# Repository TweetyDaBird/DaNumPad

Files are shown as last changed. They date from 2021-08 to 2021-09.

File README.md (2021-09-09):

## Notice!!! 
#### DaNumPad is currently under active development! Clone/Build at your own peril! Update will follow when the design has been fully build-tested!

# DaNumPad
A 'family' of mechanical numpad/macro pads that can be configured either as a classic 17-key numpad, or as a 20 key (5x4) macro pad.

- USB-C connector
- Cherry MX compatible switches
- Kailh Hotswap sockets
- Supports PCB-mounted Cherry style stabilizers
- Designed as a companion to most 60% keyboards, being the same 5 row 'height'.
- Sandwich case with top and bottom plate from FR4 material.
- Full SMD design, adapted to easily allow both SMT manufacturing and handsoldering.

## DaNumPad unWired & DaNumPad Glow
Available as two variations, wired and wireless with identical footprint, using the same plate but different PCB.

#### DaNumPad 17 Glow
- Classic 17-Key Numpad layout
- Atmega32u4 MCU
- Full Per-Key RGB
- QMK compatible

#### DaNumPad 20 Glow
- 20-Key macropad with two optional spots for rotary encoders.
- Atmega32u4 MCU
- Full Per-Key RGB
- QMK compatible

#### DaNumPad unWired
- 20-Key macropad with two optional spots for rotary encoders.
- Optional 17-Key layout on the same PCB (Requires soldering hotswap sockets on alternate placing)
- Wireless using an nRF85420 MCU
- ZMK compatible (Bluetooth)
- Can use a QMK compatible, 2.4Ghz Wireless dongle for lower latency/battery consumption. (Under development!)

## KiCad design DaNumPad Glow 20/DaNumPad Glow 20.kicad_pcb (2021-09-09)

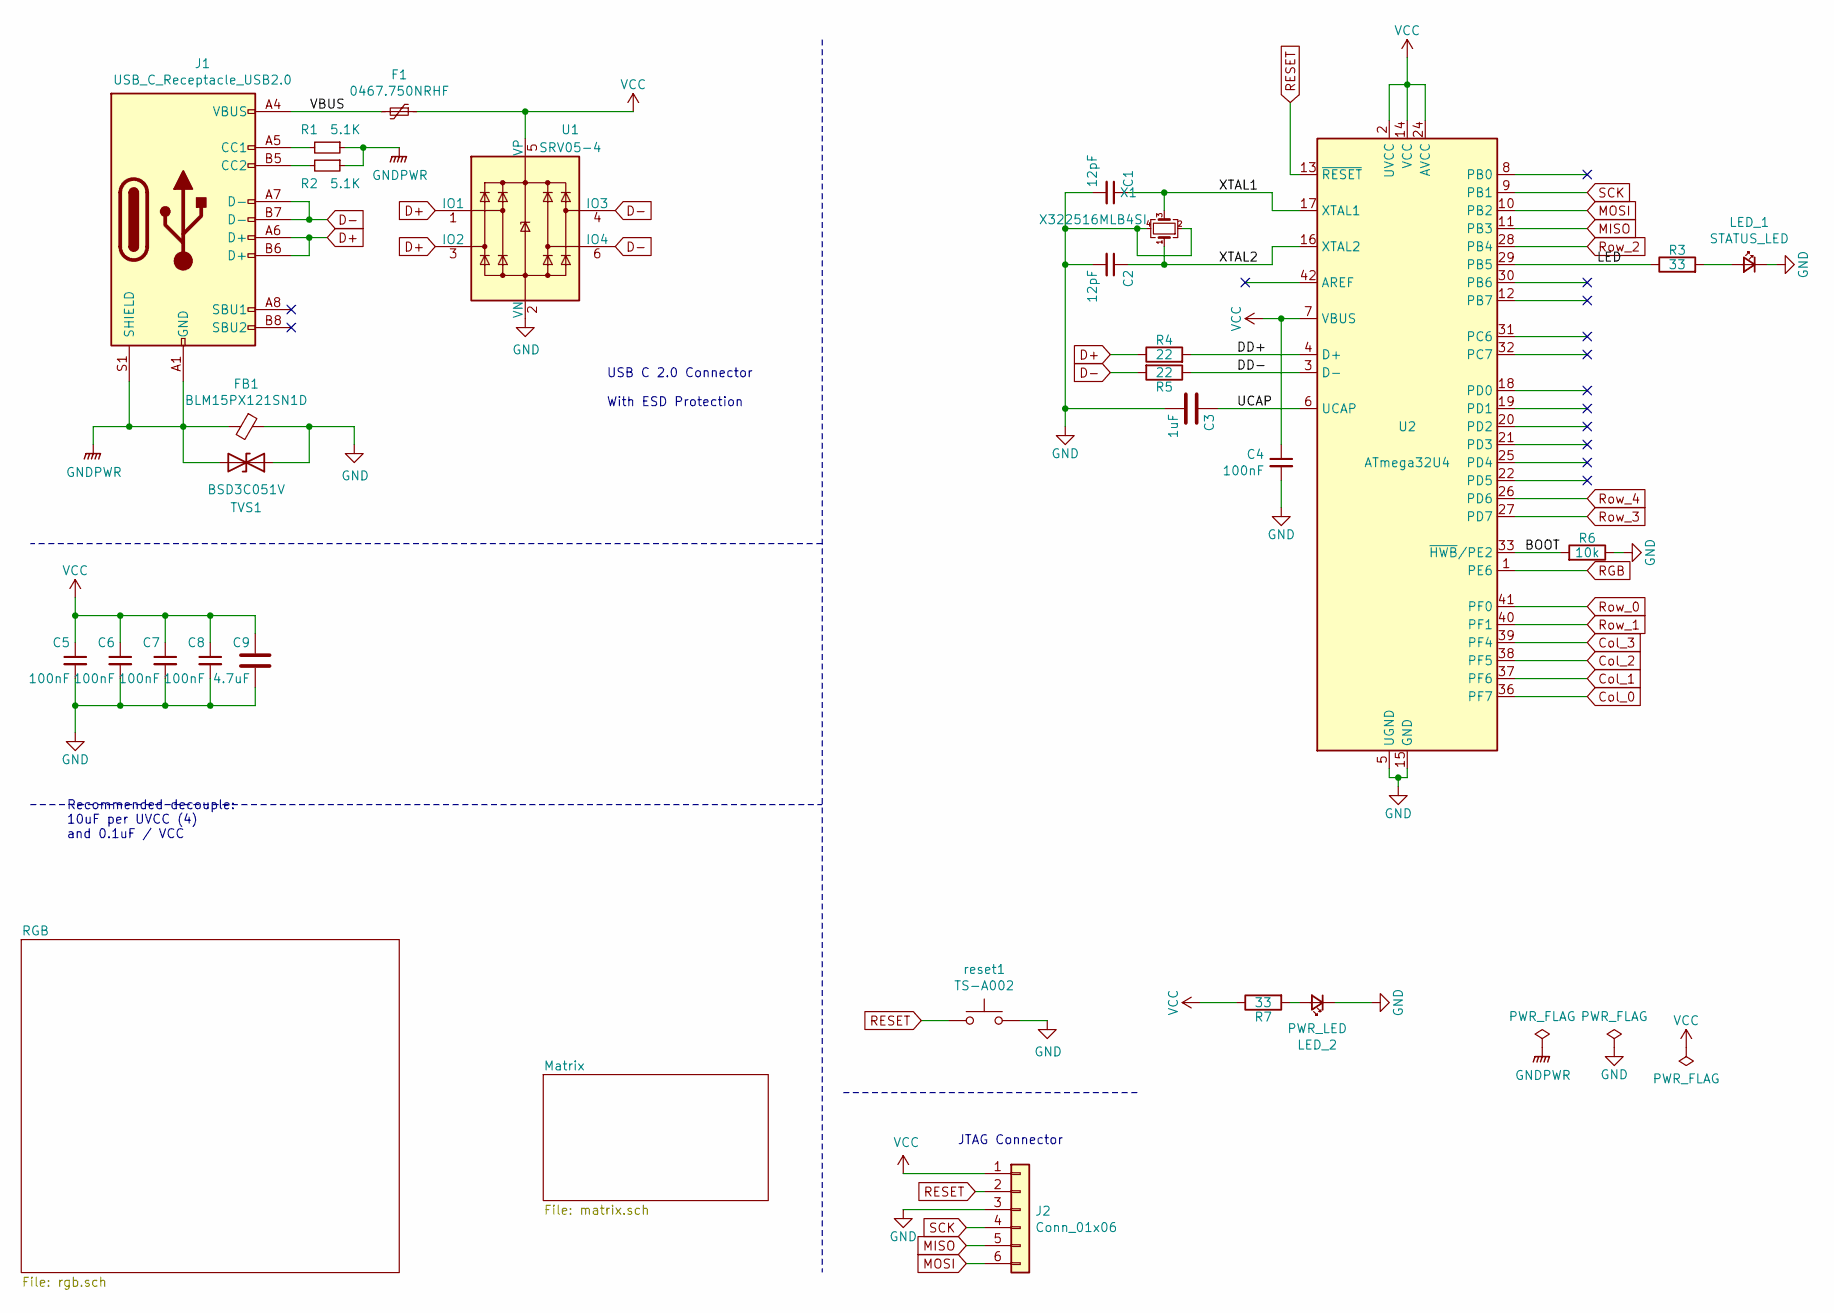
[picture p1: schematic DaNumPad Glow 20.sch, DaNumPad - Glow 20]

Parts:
C1, C2: 12pF; C_0603_1608Metric; Manufacturer_Part_Number CL10C120JB8NNNC; Mouser Part Number 581-06035A220J
C3: 1uF; C_0805_2012Metric; Manufacturer_Part_Number CL21B105KBFNNNE; Mouser Part Number 187-CL21B105KBFNNNG
C4, C5, C6, C7, C8: 100nF; C_0603_1608Metric; Manufacturer_Part_Number CC0603KRX7R9BB104; Mouser Part Number 581-06035C104JAT2A
C9: 4.7uF; C_0805_2012Metric; Manufacturer_Part_Number CL21A475KAQNNNE; Mouser Part Number 810-C2012X7R475K125C
F1: 0467.750NRHF; Fuse_0603_1608Metric_Castellated; Manufacturer_Part_Number 0467.750NRHF; LCSC C206991
FB1: BLM15PX121SN1D; R_0402_1005Metric_Pad0.72x0.64mm_HandSolder; Manufacturer_Part_Number BLM15PX121SN1D11; LCSC C88970
J1: USB_C_Receptacle_USB2.0; USB_C_Receptacle_HRO_TYPE-C-31-M-12; Manufacturer_Part_Number TYPE-C-31-M-12; LCSC C165948
J2: Conn_01x06; PinHeader_2x03_P2.54mm_Vertical
LED_1: STATUS_LED; LED_0603_1608Metric; Manufacturer_Part_Number KT-0603R; Mouser Part Number 604-APT1608EC
LED_2: PWR_LED; LED_0603_1608Metric; Manufacturer_Part_Number KT-0603R; Mouser Part Number 604-APT1608EC
R1, R2: 5.1K; R_0603_1608Metric; Manufacturer_Part_Number 0603WAF5101T5E; LCSC C23186
R3, R7: 33; R_0603_1608Metric; Manufacturer_Part_Number 0603WAF330JT5E; Mouser Part Number 667-ERJ-3EKF33R0V
R4, R5: 22; R_0603_1608Metric; Manufacturer_Part_Number 0603WAF220JT5E; Mouser Part Number 667-ERJ-3GEYJ220V
R6: 10k; R_0603_1608Metric; Manufacturer_Part_Number 0603WAF1002T5E; Mouser Part Number 667-ERJ-3GEYJ103V
TVS1: BSD3C051V; D_SOD-323; Manufacturer_Part_Number BSD3C051V; LCSC C151996
U1: SRV05-4; SOT-23-6; Manufacturer_Part_Number SRV05-4-P-T7; LCSC C85364
U2: ATmega32U4; QFN-44-1EP_7x7mm_P0.5mm_EP5.15x5.15mm; Manufacturer_Part_Number ATMEGA32U4-MU; Mouser Part Number 556-ATMEGA32U4RC-MU
X1: X322516MLB4SI; Crystal_SMD_3225-4Pin_3.2x2.5mm_HandSoldering; Mouser Part Number 81-XRCGB16M000FXN00R
reset1: TS-A002; SW_SPST_CK_RS282G05A3

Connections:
/BOOT: R6.2, U2.33 (~HWB~/PE2)
/DD+: R4.2, U2.4 (D+)
/DD-: R5.1, U2.3 (D-)
/LED: R3.1, U2.29 (PB5)
/UCAP: C3.1, U2.6 (UCAP)
/VBUS: F1.2, J1.A4 (VBUS), J1.A9 (VBUS), J1.B4 (VBUS), J1.B9 (VBUS)
/XTAL1: C1.1, U2.17 (XTAL1), X1.3
/XTAL2: C2.1, U2.16 (XTAL2), X1.1
Col_0: U2.36 (PF7); also elsewhere on the board
Col_1: U2.37 (PF6); also elsewhere on the board
Col_2: U2.38 (PF5); also elsewhere on the board
D+: J1.A6 (D+), J1.B6 (D+), R4.1, U1.1 (IO1), U1.3 (IO2)
D-: J1.A7 (D-), J1.B7 (D-), R5.2, U1.4 (IO3), U1.6 (IO4)
GND: C1.2, C2.2, C3.2, C4.2, C5.2, C6.2, C7.2, C8.2, C9.2, FB1.1, J2.3, LED_1.1 (K), LED_2.1 (K), R6.1, TVS1.1 (A1), U1.2 (VN), U2.5 (UGND), U2.15 (GND), U2.23 (GND), U2.35 (GND), U2.43 (GND), X1.2, X1.4, reset1.2; also elsewhere on the board
GNDPWR: FB1.2, J1.A1 (GND), J1.A12 (GND), J1.B1 (GND), J1.B12 (GND), J1.S1 (SHIELD), R1.1, R2.1, TVS1.2 (A2)
MISO: J2.5, U2.11 (PB3)
MOSI: J2.6, U2.10 (PB2)
unnamed: J1.A5 (CC1), R1.2
unnamed: J1.B5 (CC2), R2.2
unnamed: LED_1.2 (A), R3.2
unnamed: LED_2.2 (A), R7.2
RESET: J2.2, U2.13 (~RESET), reset1.1
RGB: U2.1 (PE6); also elsewhere on the board
Row_0: U2.41 (PF0); also elsewhere on the board
Row_1: U2.40 (PF1); also elsewhere on the board
Row_2: U2.28 (PB4); also elsewhere on the board
Row_3: U2.27 (PD7); also elsewhere on the board
Row_4: U2.26 (PD6); also elsewhere on the board
SCK: J2.4, U2.9 (PB1)
VCC: C4.1, C5.1, C6.1, C7.1, C8.1, C9.1, F1.1, J2.1, R7.1, U1.5 (VP), U2.2 (UVCC), U2.7 (VBUS), U2.14 (VCC), U2.24 (AVCC), U2.34 (VCC), U2.44 (AVCC); also elsewhere on the board

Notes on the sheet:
USB C 2.0 Connector With ESD Protection
Recommended decouple: 10uF per UVCC (4) and 0.1uF / VCC
JTAG Connector

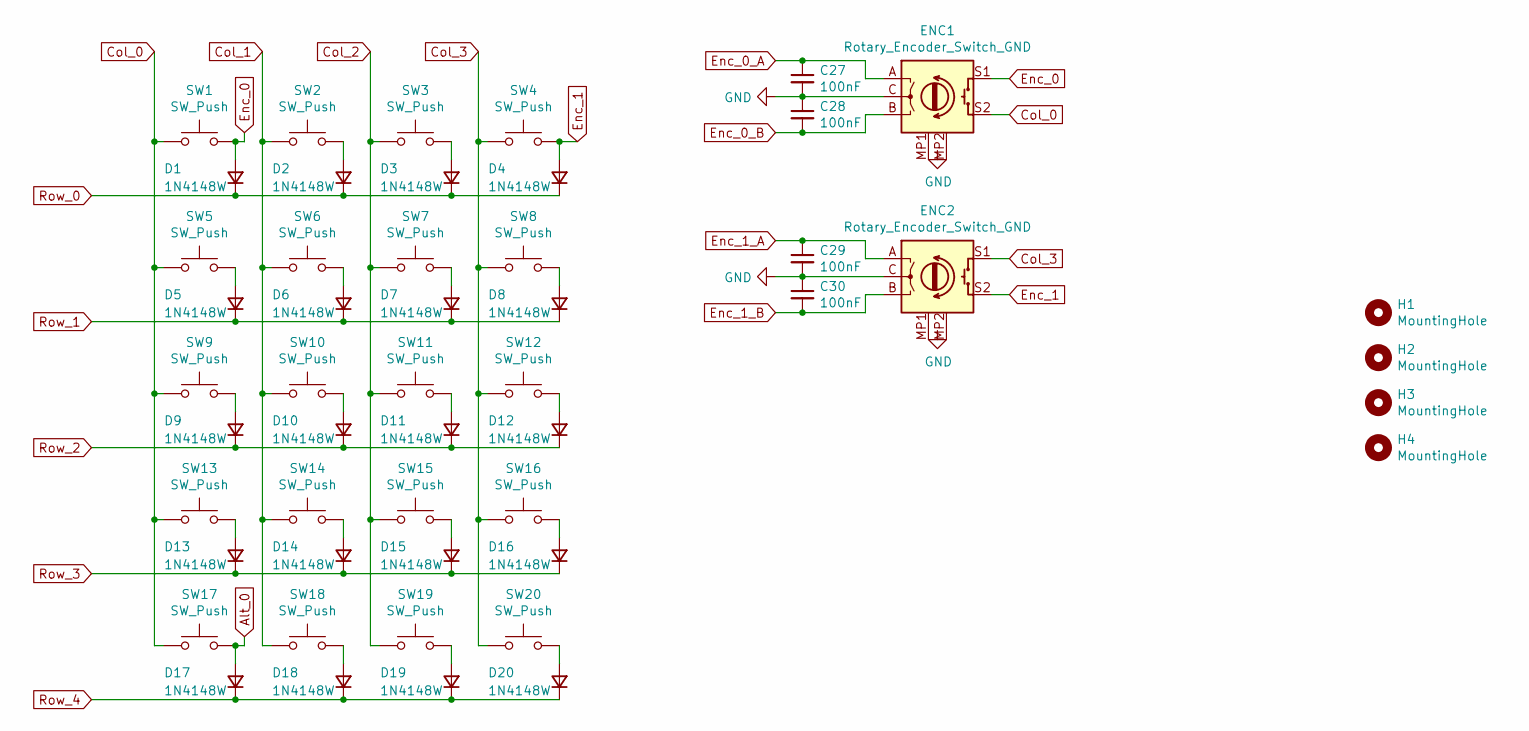
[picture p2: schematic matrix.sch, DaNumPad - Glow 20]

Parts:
C27, C28, C29, C30: 100nF; C_0603_1608Metric; Manufacturer_Part_Number CC0603KRX7R9BB104; LCSC C14663
D1, D2, D3, D4, D5, D6, D7, D8, D9, D10, D11, D12, D13, D14, D15, D16, D17, D18, D19, D20: 1N4148W; D_SOD-123; Manufacturer_Part_Number 1N4148W; LCSC C81598
ENC1, ENC2: Rotary_Encoder_Switch_GND; RotaryEncoder_Alps_EC11E-Switch_Vertical_H20mm
H1, H2, H3, H4: MountingHole; MountingHole_3.7mm
SW1, SW2, SW3, SW4, SW5, SW6, SW7, SW8, SW9, SW10, SW11, SW12, SW13, SW14, SW15, SW16, SW17, SW18, SW19, SW20: SW_Push; Kailh_socket_MX_RGB

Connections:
Alt_0: D17.2 (A), SW17.2
Col_0: ENC1.S2, SW1.1, SW5.1, SW9.1, SW13.1, SW17.1; also elsewhere on the board
Col_1: SW2.1, SW6.1, SW10.1, SW14.1, SW18.1; also elsewhere on the board
Col_2: SW3.1, SW7.1, SW11.1, SW15.1, SW19.1; also elsewhere on the board
Enc_0: D1.2 (A), ENC1.S1, SW1.2
Enc_0_A: C27.1, ENC1.A
Enc_0_B: C28.2, ENC1.B
Enc_1_A: C29.1, ENC2.A
Enc_1_B: C30.2, ENC2.B
GND: C27.2, C28.1, C29.2, C30.1, ENC1.C, ENC1.MP2 (GND), ENC2.C, ENC2.MP2 (GND); also elsewhere on the board
unnamed: D2.2 (A), SW2.2
unnamed: D3.2 (A), SW3.2
unnamed: D5.2 (A), SW5.2
unnamed: D6.2 (A), SW6.2
unnamed: D7.2 (A), SW7.2
unnamed: D9.2 (A), SW9.2
unnamed: D10.2 (A), SW10.2
unnamed: D11.2 (A), SW11.2
unnamed: D12.2 (A), SW12.2
unnamed: D13.2 (A), SW13.2
unnamed: D14.2 (A), SW14.2
unnamed: D15.2 (A), SW15.2
unnamed: D18.2 (A), SW18.2
unnamed: D19.2 (A), SW19.2
unnamed: D20.2 (A), SW20.2
Row_0: D1.1 (K), D2.1 (K), D3.1 (K), D4.1 (K); also elsewhere on the board
Row_1: D5.1 (K), D6.1 (K), D7.1 (K), D8.1 (K); also elsewhere on the board
Row_2: D9.1 (K), D10.1 (K), D11.1 (K), D12.1 (K); also elsewhere on the board
Row_3: D13.1 (K), D14.1 (K), D15.1 (K), D16.1 (K); also elsewhere on the board
Row_4: D17.1 (K), D18.1 (K), D19.1 (K), D20.1 (K); also elsewhere on the board

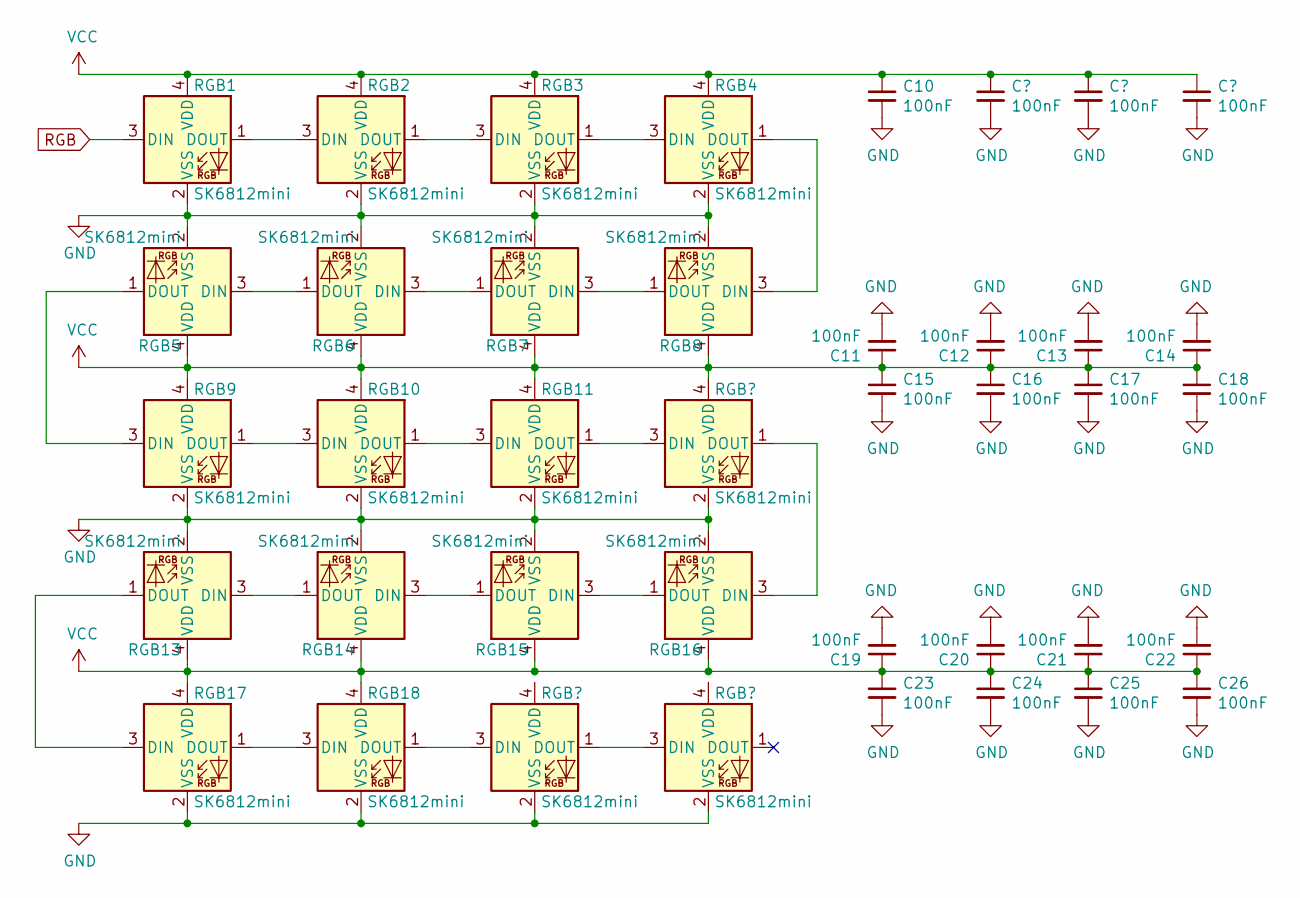
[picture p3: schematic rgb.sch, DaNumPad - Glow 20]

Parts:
C10, C11, C12, C13, C14, C15, C16, C17, C18, C19, C20, C21, C22, C23, C24, C25, C26: 100nF; C_0603_1608Metric; Manufacturer_Part_Number CC0603KRX7R9BB104; LCSC C14663
RGB1, RGB2, RGB3, RGB4, RGB5, RGB6, RGB7, RGB8, RGB9, RGB10, RGB11, RGB13, RGB14, RGB15, RGB16, RGB17, RGB18: SK6812mini; SK6812MINI_Midmount

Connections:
GND: C10.2, C11.2, C12.2, C13.2, C14.2, C15.2, C16.2, C17.2, C18.2, C19.2, C20.2, C21.2, C22.2, C23.2, C24.2, C25.2, C26.2, RGB1.2 (VSS), RGB2.2 (VSS), RGB3.2 (VSS), RGB4.2 (VSS), RGB5.2 (VSS), RGB6.2 (VSS), RGB7.2 (VSS), RGB8.2 (VSS), RGB9.2 (VSS), RGB10.2 (VSS), RGB11.2 (VSS), RGB13.2 (VSS), RGB14.2 (VSS), RGB15.2 (VSS), RGB16.2 (VSS), RGB17.2 (VSS), RGB18.2 (VSS); also elsewhere on the board
unnamed: RGB1.1 (DOUT), RGB2.3 (DIN)
unnamed: RGB2.1 (DOUT), RGB3.3 (DIN)
unnamed: RGB3.1 (DOUT), RGB4.3 (DIN)
unnamed: RGB4.1 (DOUT), RGB8.3 (DIN)
unnamed: RGB5.1 (DOUT), RGB9.3 (DIN)
unnamed: RGB5.3 (DIN), RGB6.1 (DOUT)
unnamed: RGB6.3 (DIN), RGB7.1 (DOUT)
unnamed: RGB7.3 (DIN), RGB8.1 (DOUT)
unnamed: RGB10.1 (DOUT), RGB11.3 (DIN)
unnamed: RGB9.1 (DOUT), RGB10.3 (DIN)
unnamed 52: RGB11.1 (DOUT); also elsewhere on the board
unnamed 53: RGB16.3 (DIN); also elsewhere on the board
unnamed: RGB13.1 (DOUT), RGB17.3 (DIN)
unnamed: RGB13.3 (DIN), RGB14.1 (DOUT)
unnamed: RGB14.3 (DIN), RGB15.1 (DOUT)
unnamed: RGB15.3 (DIN), RGB16.1 (DOUT)
unnamed: RGB17.1 (DOUT), RGB18.3 (DIN)
unnamed 59: RGB18.1 (DOUT); also elsewhere on the board
RGB: RGB1.3 (DIN); also elsewhere on the board
VCC: C10.1, C11.1, C12.1, C13.1, C14.1, C15.1, C16.1, C17.1, C18.1, C19.1, C20.1, C21.1, C22.1, C23.1, C24.1, C25.1, C26.1, RGB1.4 (VDD), RGB2.4 (VDD), RGB3.4 (VDD), RGB4.4 (VDD), RGB5.4 (VDD), RGB6.4 (VDD), RGB7.4 (VDD), RGB8.4 (VDD), RGB9.4 (VDD), RGB10.4 (VDD), RGB11.4 (VDD), RGB13.4 (VDD), RGB14.4 (VDD), RGB15.4 (VDD), RGB16.4 (VDD), RGB17.4 (VDD), RGB18.4 (VDD); also elsewhere on the board

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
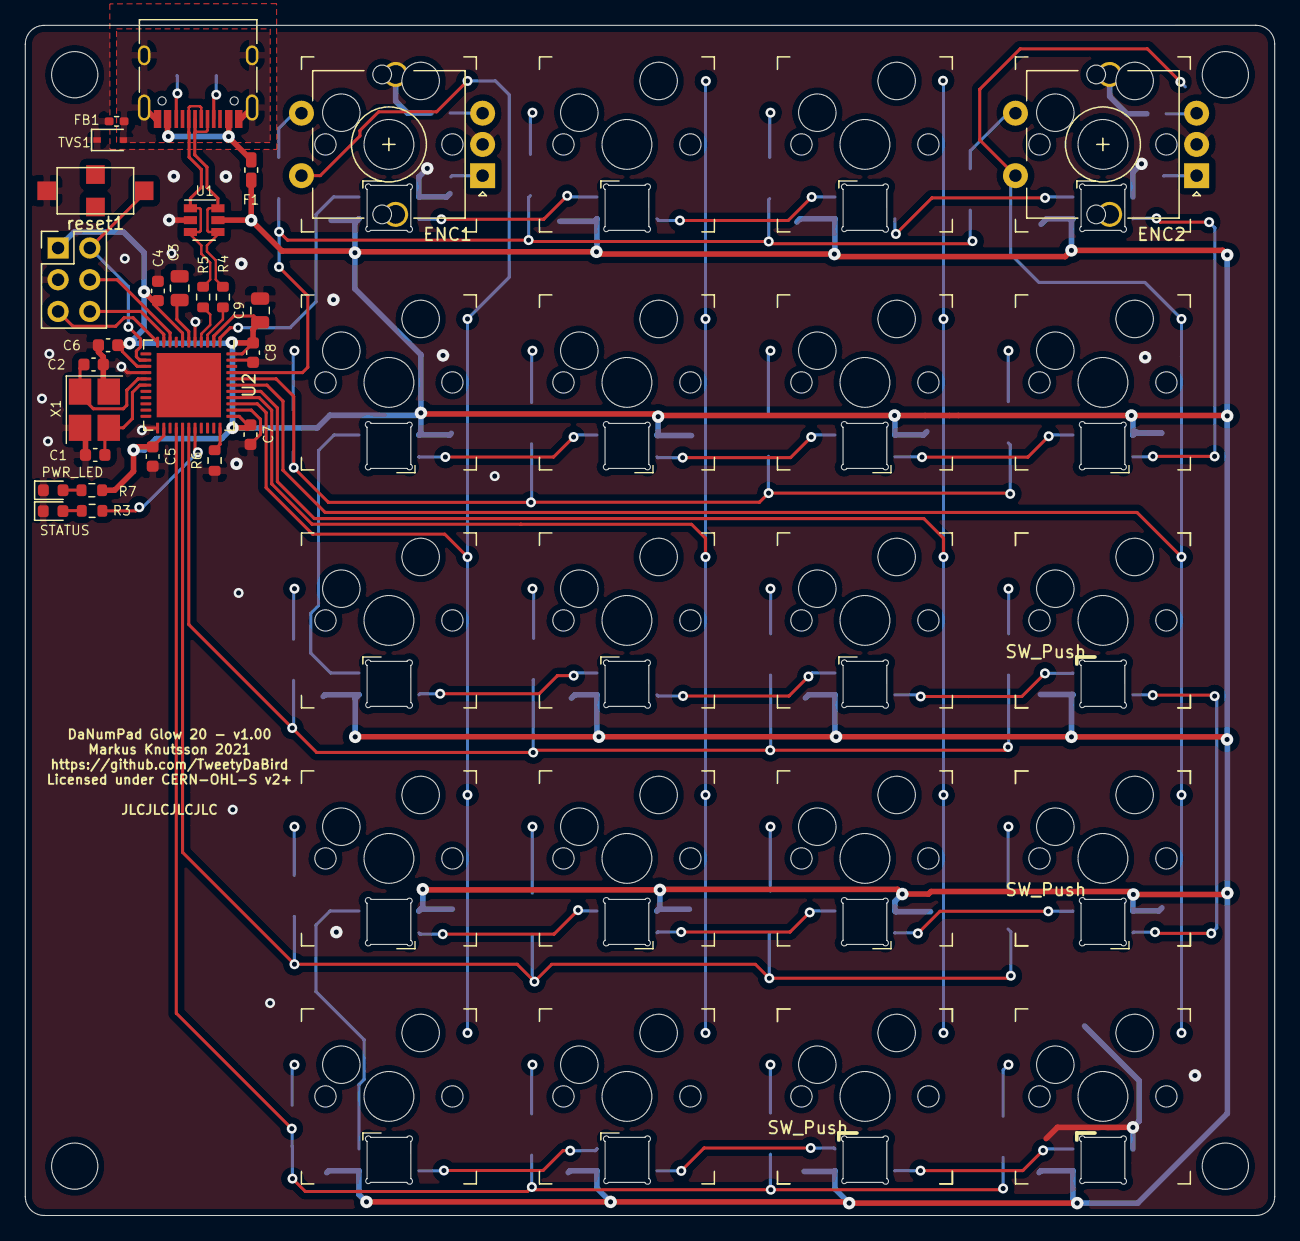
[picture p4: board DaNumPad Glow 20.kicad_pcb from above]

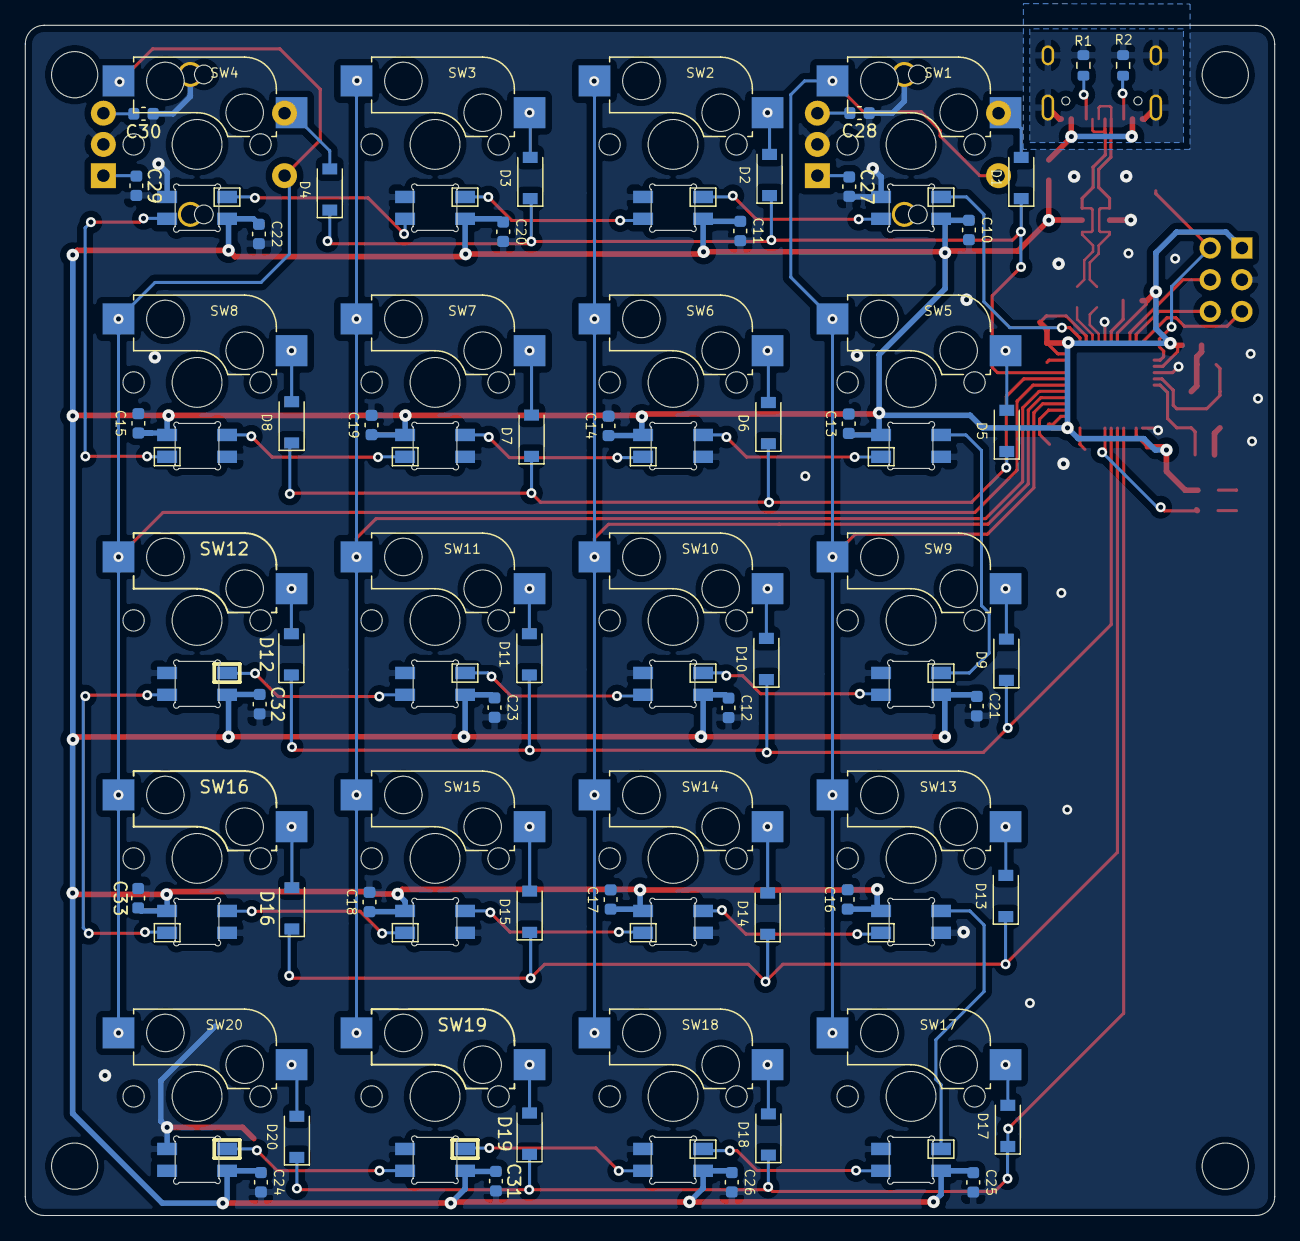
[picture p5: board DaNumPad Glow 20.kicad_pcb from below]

Board: 2 copper layers, 100.0 x 95.3 mm, 117 parts (46 on the bottom side), 74 nets.

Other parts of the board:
C31, C32, C33: 100nF; C_0603_1608Metric
RGB12, RGB19, RGB20: SK6812mini; SK6812MINI_Midmount

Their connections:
GND: C31.2, C32.2, C33.2, RGB12.2, RGB19.2, RGB20.2; also elsewhere on the board
unnamed 52: RGB12.3; also elsewhere on the board
unnamed 53: RGB12.1; also elsewhere on the board
unnamed 59: RGB19.3; also elsewhere on the board
unnamed: RGB19.1, RGB20.3
VCC: C31.1, C32.1, C33.1, RGB12.4, RGB19.4, RGB20.4; also elsewhere on the board

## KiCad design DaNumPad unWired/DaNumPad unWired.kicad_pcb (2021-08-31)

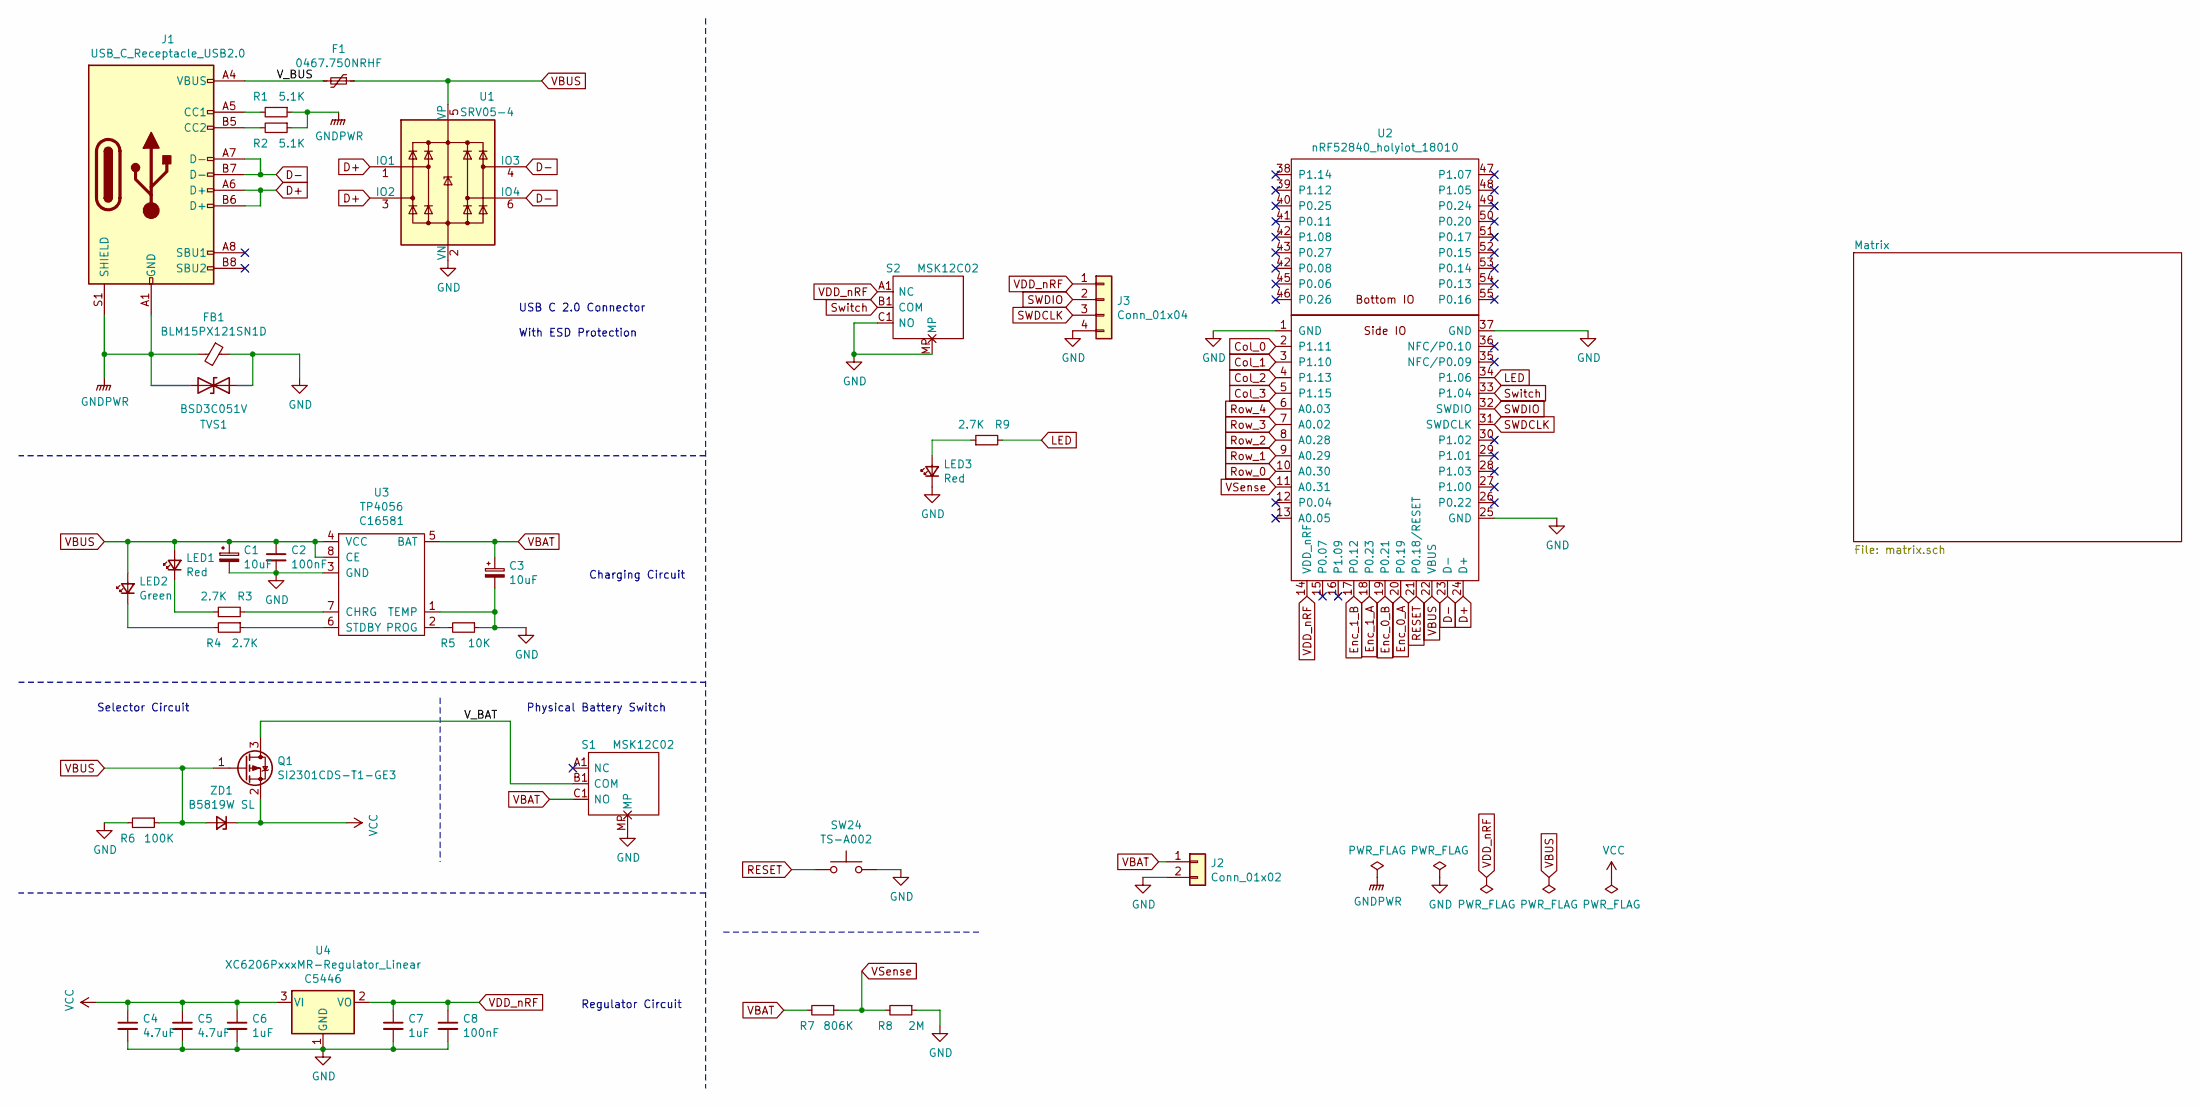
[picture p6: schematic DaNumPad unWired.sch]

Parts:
C1, C3: 10uF; CP_EIA-3216-18_Kemet-A; Manufacturer_Part_Number CA45-A-10V-10uF-M; LCSC C128256
C2, C8: 100nF; C_0603_1608Metric; Manufacturer_Part_Number CC0603KRX7R9BB104; LCSC C14663
C4, C5: 4.7uF; C_0603_1608Metric; Manufacturer_Part_Number CL10A475KO8NNNC; LCSC C19666
C6, C7: 1uF; C_0603_1608Metric; Manufacturer_Part_Number CL10A105KB8NNNC; LCSC C15849
F1: 0467.750NRHF; Fuse_0603_1608Metric_Castellated; Manufacturer_Part_Number 0467.750NRHF; LCSC C206991
FB1: BLM15PX121SN1D; R_0402_1005Metric_Pad0.72x0.64mm_HandSolder; Manufacturer_Part_Number BLM15PX121SN1D11; LCSC C882964
J1: USB_C_Receptacle_USB2.0; USB_C_Receptacle_HRO_TYPE-C-31-M-12; Manufacturer_Part_Number TYPE-C-31-M-12; LCSC C165948
J2: Conn_01x02; JST_PH_S2B-PH-K_1x02_P2.00mm_Horizontal; Manufacturer_Part_Number A2001WV-2P; LCSC C225188
J3: Conn_01x04; PinHeader_1x04_P2.54mm_Vertical
LED1, LED3: Red; LED_0603_1608Metric; Manufacturer_Part_Number KT-0603R; LCSC C2286
LED2: Green; LED_0603_1608Metric; Manufacturer_Part_Number 19-217/GHC-YR1S2/3T; LCSC C72043
Q1: SI2301CDS-T1-GE3; SOT-23; Manufacturer_Part_Number SI2301CDS-T1-GE3; LCSC C10487
R1, R2: 5.1K; R_0603_1608Metric; Manufacturer_Part_Number 0603WAF5101T5E; LCSC C23186
R3, R4, R9: 2.7K; R_0603_1608Metric; Manufacturer_Part_Number 0603WAF2701T5E; LCSC C13167
R5: 10K; R_0603_1608Metric; Manufacturer_Part_Number 0603WAF1002T5E; LCSC C25804
R6: 100K; R_0603_1608Metric; Manufacturer_Part_Number 0603WAF1003T5E; LCSC C25803
R7: 806K; R_0603_1608Metric; Manufacturer_Part_Number RMC0603806K1%N; LCSC C269512
R8: 2M; R_0603_1608Metric; Manufacturer_Part_Number 0603WAF2004T5E; LCSC C22976
S1, S2: MSK12C02; Manufacturer_Part_Number MSK12C02; LCSC C431540
SW24: TS-A002; SW_SPST_CK_RS282G05A3
TVS1: BSD3C051V; D_SOD-323; Manufacturer_Part_Number BSD3C051V; LCSC C151996
U1: SRV05-4; SOT-23-6; Manufacturer_Part_Number SRV05-4-P-T7; LCSC C85364
U2: nRF52840_holyiot_18010; nRF52840_holyiot_18010_HS_simple
U3: TP4056; SOIC127P600X175-9N; Manufacturer_Part_Number TP4056-42-ESOP8; LCSC C16581
U4: XC6206PxxxMR-Regulator_Linear; SOT-23; Manufacturer_Part_Number XC6206P332MR; LCSC C5446
ZD1: B5819W SL; D_SOD-123; Manufacturer_Part_Number B5819W SL; LCSC C8598

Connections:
/V_BAT: Q1.3 (D), S1.B1 (COM)
/V_BUS: F1.2, J1.A4 (VBUS), J1.A9 (VBUS), J1.B4 (VBUS), J1.B9 (VBUS)
Col_0: U2.2 (P1.11); also elsewhere on the board
Col_1: U2.3 (P1.10); also elsewhere on the board
Col_2: U2.4 (P1.13); also elsewhere on the board
Col_3: U2.5 (P1.15); also elsewhere on the board
D+: J1.A6 (D+), J1.B6 (D+), U1.1 (IO1), U1.3 (IO2), U2.24 (D+)
D-: J1.A7 (D-), J1.B7 (D-), U1.4 (IO3), U1.6 (IO4), U2.23 (D-)
Enc_0_A: U2.20 (P0.19); also elsewhere on the board
Enc_0_B: U2.19 (P0.21); also elsewhere on the board
Enc_1_A: U2.18 (P0.23); also elsewhere on the board
Enc_1_B: U2.17 (P0.12); also elsewhere on the board
GND: C1.2, C2.2, C3.2, C4.2, C5.2, C6.2, C7.2, C8.2, FB1.1, J2.2, J3.4, LED3.1 (K), R5.1, R6.2, R8.1, S1.MP, S2.C1 (NO), S2.MP, SW24.2, TVS1.1 (A1), U1.2 (VN), U2.1 (GND), U2.25 (GND), U2.37 (GND), U3.1 (TEMP), U3.3 (GND), U4.1 (GND); also elsewhere on the board
GNDPWR: FB1.2, J1.A1 (GND), J1.A12 (GND), J1.B1 (GND), J1.B12 (GND), J1.S1 (SHIELD), R1.1, R2.1, TVS1.2 (A2)
LED: R9.2, U2.34 (P1.06)
unnamed: J1.A5 (CC1), R1.2
unnamed: J1.B5 (CC2), R2.2
unnamed: LED1.1 (K), R3.1
unnamed: LED2.1 (K), R4.2
unnamed: LED3.2 (A), R9.1
unnamed: R3.2, U3.7 (CHRG)
unnamed: R4.1, U3.6 (STDBY)
unnamed: R5.2, U3.2 (PROG)
RESET: SW24.1, U2.21 (P0.18/RESET)
Row_0: U2.10 (A0.30); also elsewhere on the board
Row_1: U2.9 (A0.29); also elsewhere on the board
Row_2: U2.8 (A0.28); also elsewhere on the board
Row_3: U2.7 (A0.02); also elsewhere on the board
Row_4: U2.6 (A0.03); also elsewhere on the board
SWDCLK: J3.3, U2.31 (SWDCLK)
SWDIO: J3.2, U2.32 (SWDIO)
Switch: S2.B1 (COM), U2.33 (P1.04)
VBAT: C3.1, J2.1, R7.2, S1.C1 (NO), U3.5 (BAT)
VBUS: C1.1, C2.1, F1.1, LED1.2 (A), LED2.2 (A), Q1.1 (G), R6.1, U1.5 (VP), U2.22 (VBUS), U3.4 (VCC), U3.8 (CE), ZD1.2 (A)
VCC: C4.1, C5.1, C6.1, Q1.2 (S), U4.3 (VI), ZD1.1 (K)
VDD_nRF: C7.1, C8.1, J3.1, S2.A1 (NC), U2.14 (VDD_nRF), U4.2 (VO)
VSense: R7.1, R8.2, U2.11 (A0.31)

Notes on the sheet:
Selector Circuit
Physical Battery Switch
Charging Circuit
Regulator Circuit
USB C 2.0 Connector With ESD Protection

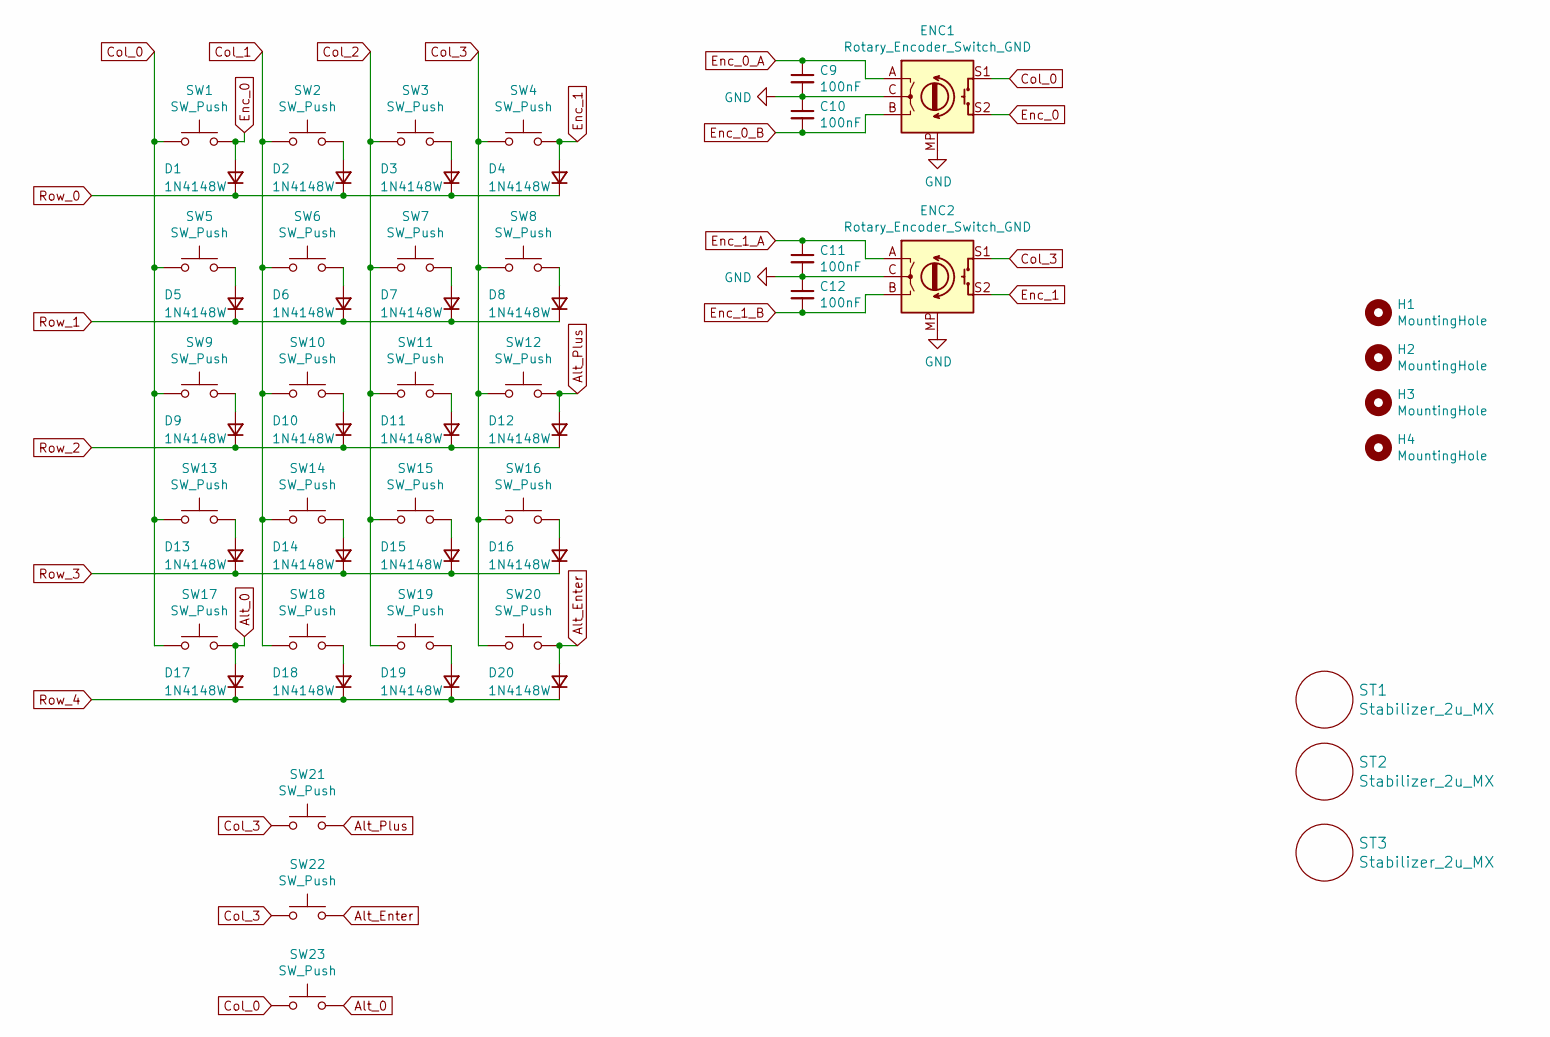
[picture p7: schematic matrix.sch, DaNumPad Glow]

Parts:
C9, C10, C11, C12: 100nF; C_0603_1608Metric; Manufacturer_Part_Number CC0603KRX7R9BB104; LCSC C14663
D1, D2, D3, D4, D5, D6, D7, D8, D9, D10, D11, D12, D13, D14, D15, D16, D17, D18, D19, D20: 1N4148W; D_SOD-123; Manufacturer_Part_Number 1N4148W; LCSC C81598
ENC1, ENC2: Rotary_Encoder_Switch_GND; RotaryEncoder_Alps_EC11E-Switch_Vertical_H20mm
H1, H2, H3, H4: MountingHole; MountingHole_3.7mm
ST1, ST2, ST3: Stabilizer_2u_MX; Stabilizer_MX_2u
SW1, SW2, SW3, SW4, SW5, SW6, SW7, SW8, SW9, SW10, SW11, SW12, SW13, SW14, SW15, SW16, SW17, SW18, SW19, SW20, SW21, SW22, SW23: SW_Push; Kailh_socket_MX_RGB

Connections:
Alt_0: D17.2 (A), SW17.2, SW23.2
Alt_Enter: D20.2 (A), SW20.2, SW22.1
Alt_Plus: D12.2 (A), SW12.2, SW21.1
Col_0: ENC1.S1, SW1.1, SW5.1, SW9.1, SW13.1, SW17.1, SW23.1; also elsewhere on the board
Col_1: SW2.1, SW6.1, SW10.1, SW14.1, SW18.1; also elsewhere on the board
Col_2: SW3.1, SW7.1, SW11.1, SW15.1, SW19.1; also elsewhere on the board
Col_3: ENC2.S1, SW4.1, SW8.2, SW12.1, SW16.2, SW20.1, SW21.2, SW22.2; also elsewhere on the board
Enc_0: D1.2 (A), ENC1.S2, SW1.2
Enc_0_A: C9.1, ENC1.A; also elsewhere on the board
Enc_0_B: C10.2, ENC1.B; also elsewhere on the board
Enc_1: D4.2 (A), ENC2.S2, SW4.2
Enc_1_A: C11.1, ENC2.A; also elsewhere on the board
Enc_1_B: C12.2, ENC2.B; also elsewhere on the board
GND: C9.2, C10.1, C11.2, C12.1, ENC1.C, ENC1.MP (GND), ENC2.C, ENC2.MP (GND); also elsewhere on the board
unnamed: D2.2 (A), SW2.2
unnamed: D3.2 (A), SW3.2
unnamed: D5.2 (A), SW5.2
unnamed: D6.2 (A), SW6.2
unnamed: D7.2 (A), SW7.2
unnamed: D8.2 (A), SW8.1
unnamed: D9.2 (A), SW9.2
unnamed: D10.2 (A), SW10.2
unnamed: D11.2 (A), SW11.2
unnamed: D13.2 (A), SW13.2
unnamed: D14.2 (A), SW14.2
unnamed: D15.2 (A), SW15.2
unnamed: D16.2 (A), SW16.1
unnamed: D18.2 (A), SW18.2
unnamed: D19.2 (A), SW19.2
Row_0: D1.1 (K), D2.1 (K), D3.1 (K), D4.1 (K); also elsewhere on the board
Row_1: D5.1 (K), D6.1 (K), D7.1 (K), D8.1 (K); also elsewhere on the board
Row_2: D9.1 (K), D10.1 (K), D11.1 (K), D12.1 (K); also elsewhere on the board
Row_3: D13.1 (K), D14.1 (K), D15.1 (K), D16.1 (K); also elsewhere on the board
Row_4: D17.1 (K), D18.1 (K), D19.1 (K), D20.1 (K); also elsewhere on the board

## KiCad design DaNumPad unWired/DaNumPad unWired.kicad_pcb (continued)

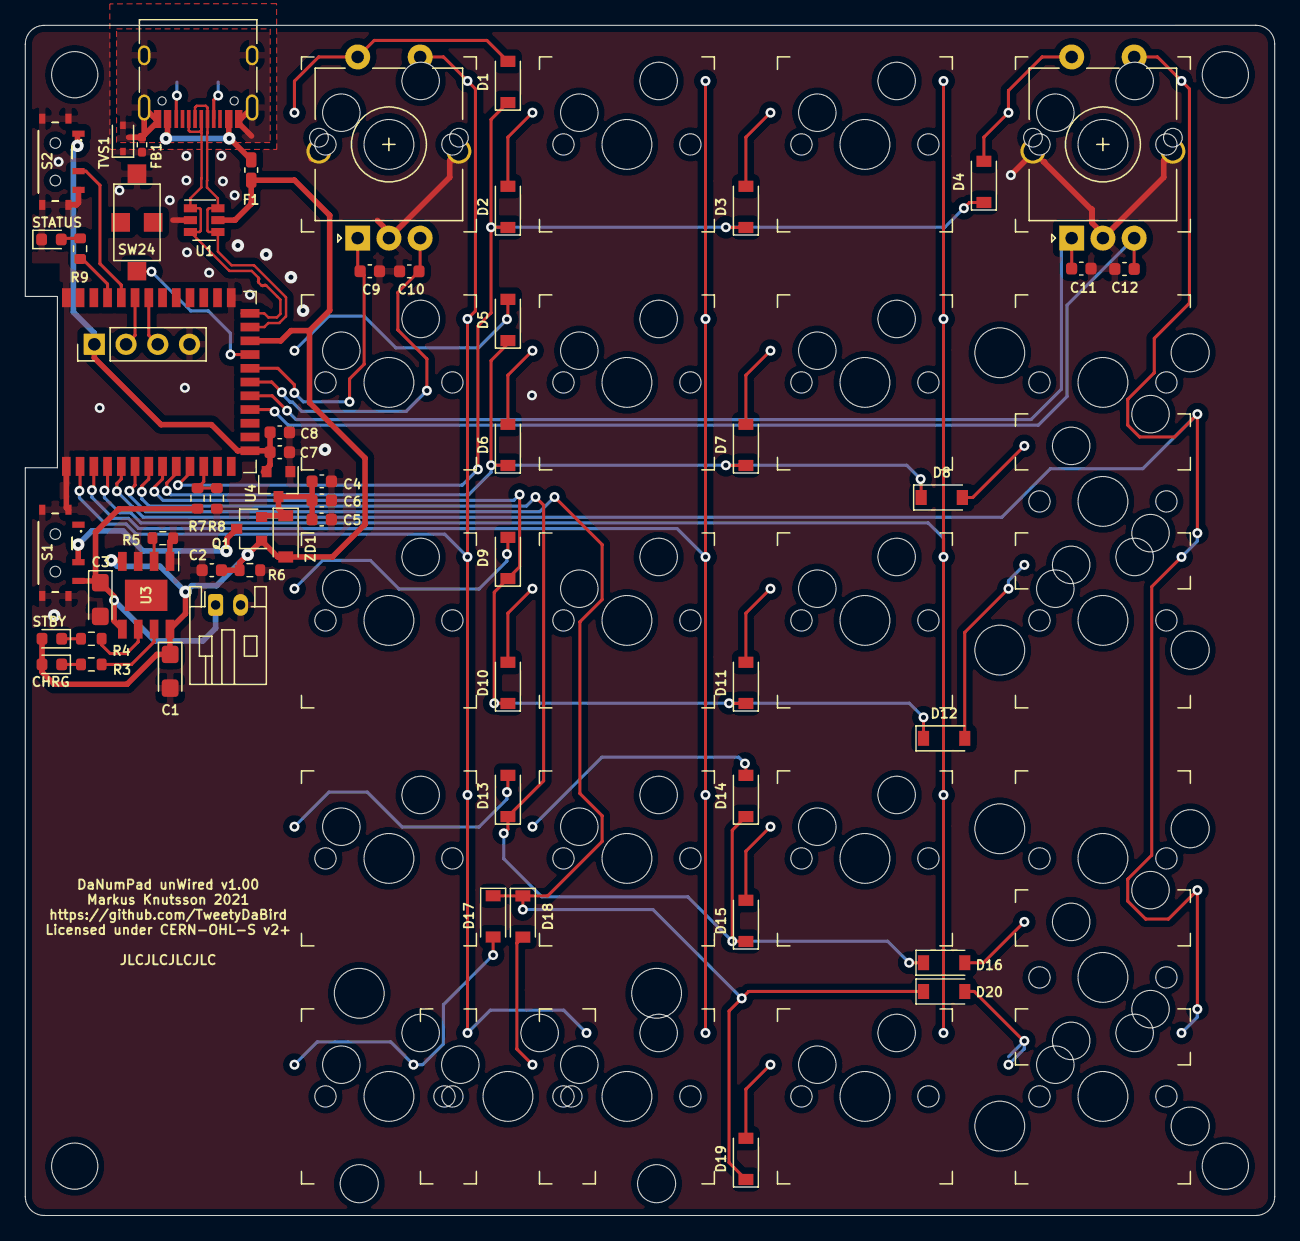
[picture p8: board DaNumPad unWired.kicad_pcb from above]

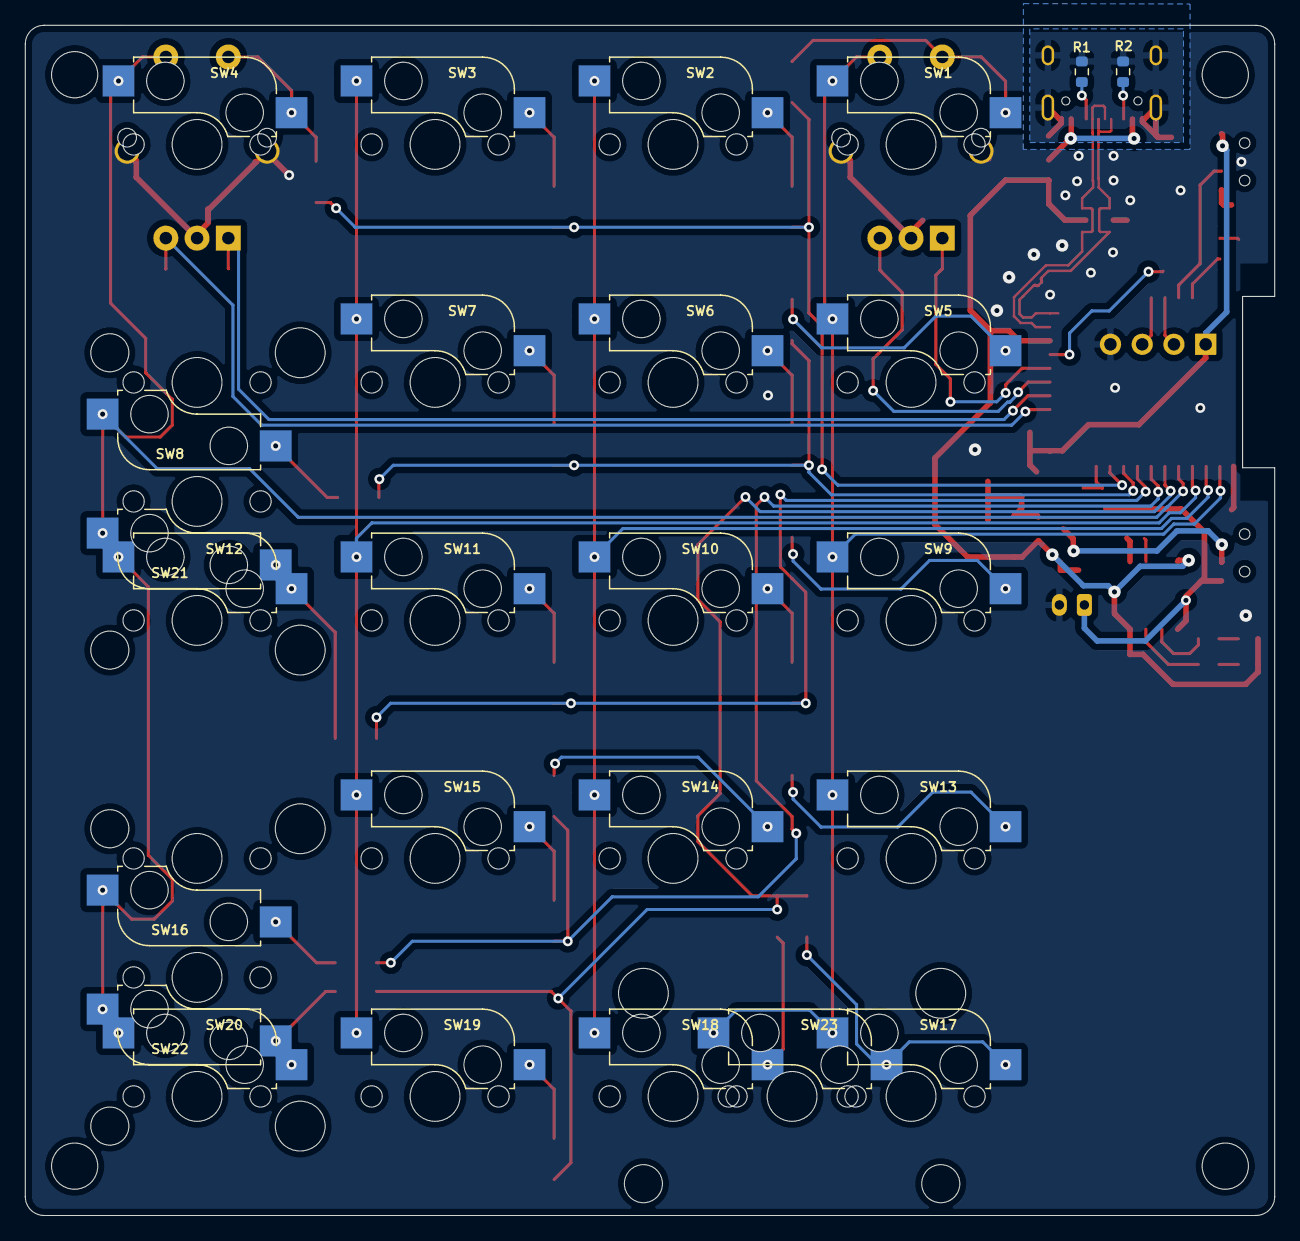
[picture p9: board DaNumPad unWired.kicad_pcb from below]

Board: 2 copper layers, 100.0 x 95.3 mm, 91 parts (2 on the bottom side), 57 nets.

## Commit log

2021-08-25 Added silkscreen and PCB Plates
    [DaNumPad Bottom Plate.kicad_pcb, DaNumPad Bottom Plate.sch, DaNumPad Top Plate.kicad_pcb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]
2021-08-25 Updated plates
    [DaNumPad Top Plate.kicad_pcb]
2021-08-25 Deleted old files
    [DaNumPad unWired.kicad_pcb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]
2021-08-30 Glow version redesign
    For now, it's 17 keys only.
    [DaNumPad Glow 17.kicad_pcb, DaNumPad Glow 17.sch, DaNumPad Glow.kicad_pcb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]
2021-08-31 Finalized licensing on PCB files
    [DaNumPad Glow 17.kicad_pcb, DaNumPad Glow 17.sch, DaNumPad unWired.kicad_pcb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]
2021-08-31 Cleanup of silkscreen
    [DaNumPad Glow 17.kicad_pcb, DaNumPad Glow 17.sch, matrix 17.sch]
2021-09-09 Added Glow 20 key version
    [DaNumPad Glow 17.kicad_pcb, DaNumPad Glow 17.sch, DaNumPad Glow 20.kicad_pcb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]

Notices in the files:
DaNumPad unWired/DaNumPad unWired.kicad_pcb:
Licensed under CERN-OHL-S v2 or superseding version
